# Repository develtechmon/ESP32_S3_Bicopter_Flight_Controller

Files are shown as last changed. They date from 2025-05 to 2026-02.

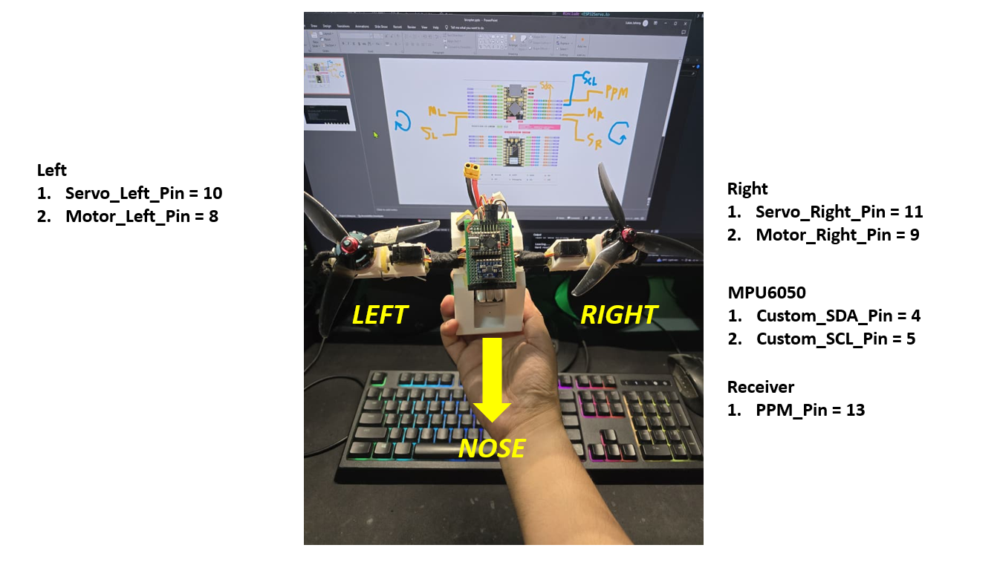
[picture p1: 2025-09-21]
Schematic/Schematic.PNG

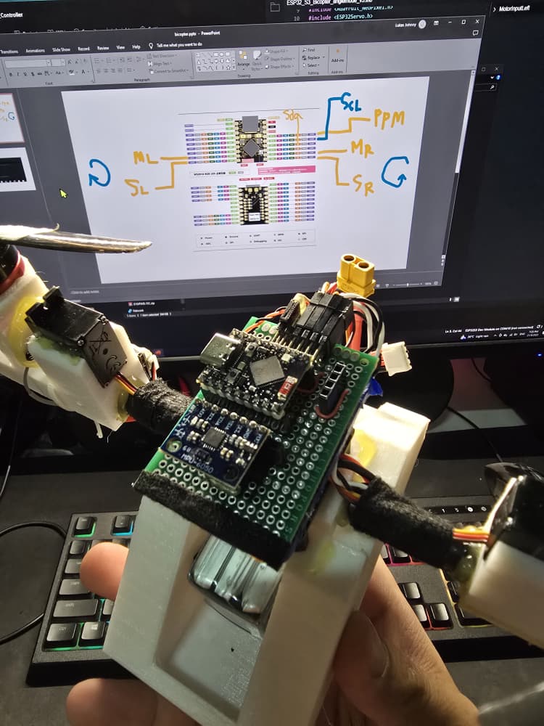
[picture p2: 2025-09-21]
Images/V2_Bicopter/2.jpeg

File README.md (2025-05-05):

# ESP32_S3_Bicopter_Flight_Controller
This is repository for EESP32_S3_Bicopter_Flight_Controller Drone. This is meant for 5inch drone build

## Components For Drone
| **Components** | **Quantity** |
|---|---|
| ESP32 S3 Super Mini | 1 |
| MPU6050 | 1 |
| Atmel 45A ESC | 2 |
| Flysky FS-A8S 2.4G 8CH | 1 |
| Servo SG90 | 2 |
| A2212/15T 930KV | 2 |
| Jumpter T-Lite V2 transmitter | 1 |
| Lipo 4S Battery | 1 |
| 3 blades 5 inch propeller | 2 |

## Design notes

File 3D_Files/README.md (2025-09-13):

This directory consist 3D stl use for this project

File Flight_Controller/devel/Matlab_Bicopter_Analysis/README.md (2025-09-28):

1. Refer to claud Bicopter PID tuning in MATLAB

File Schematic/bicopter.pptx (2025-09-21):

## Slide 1

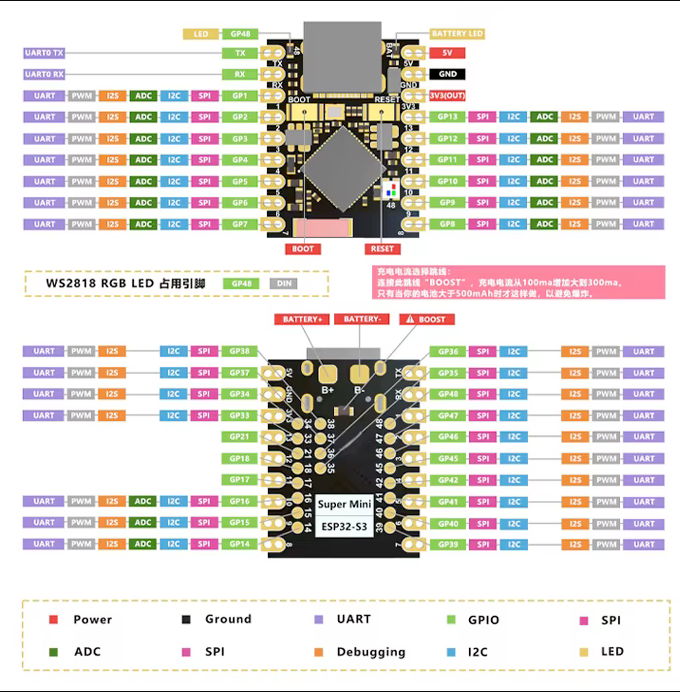
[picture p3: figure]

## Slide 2

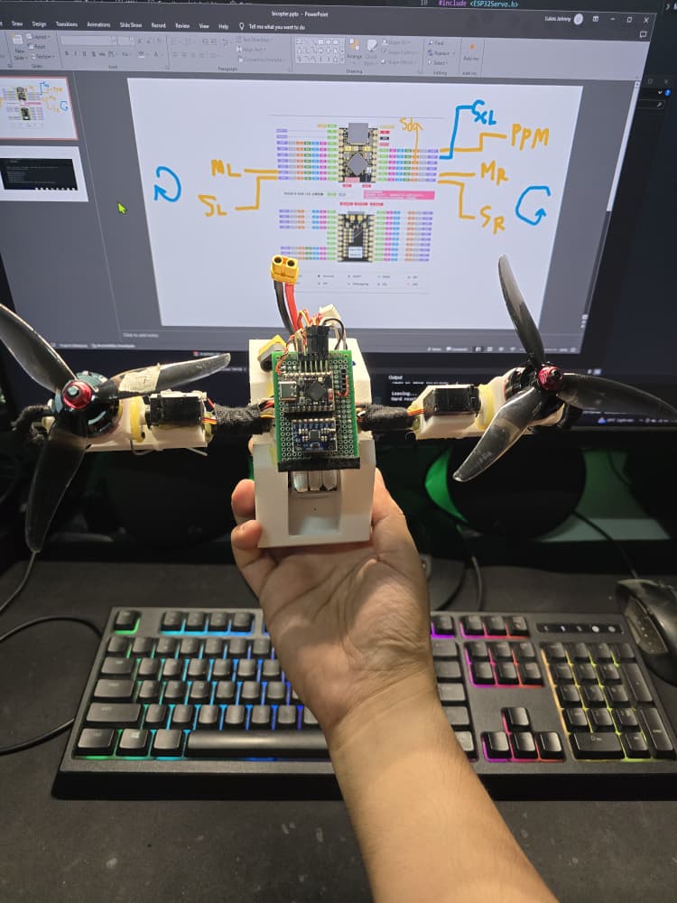
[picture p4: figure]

Left
1. Servo_Left_Pin = 10
2. Motor_Left_Pin = 8

Right
1. Servo_Right_Pin = 11
2. Motor_Right_Pin = 9

LEFT

RIGHT

MPU6050
1. Custom_SDA_Pin = 4
2. Custom_SCL_Pin = 5

Receiver
1. PPM_Pin = 13

NOSE

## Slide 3

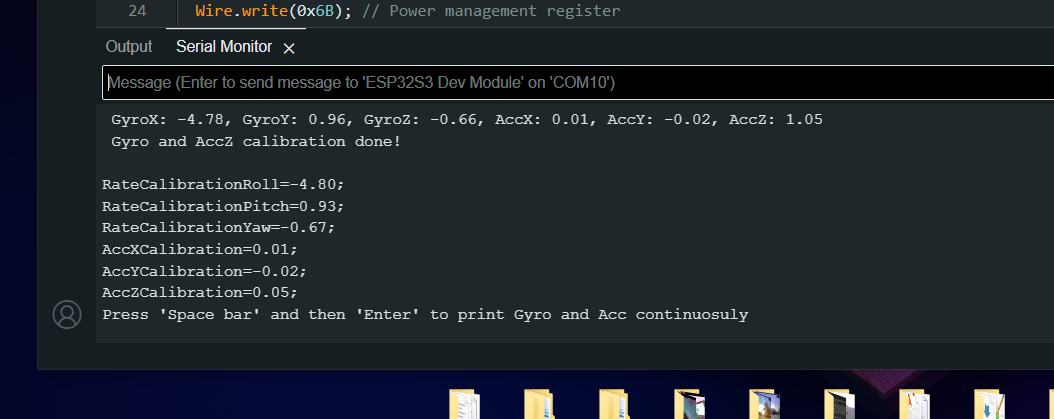
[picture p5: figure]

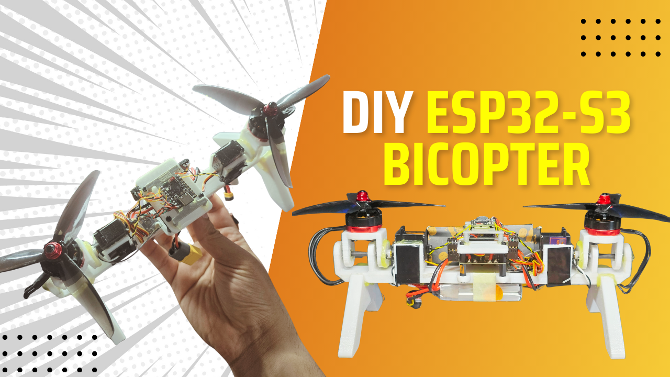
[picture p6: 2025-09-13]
Images/EsP32-S3 Flight Controller.png

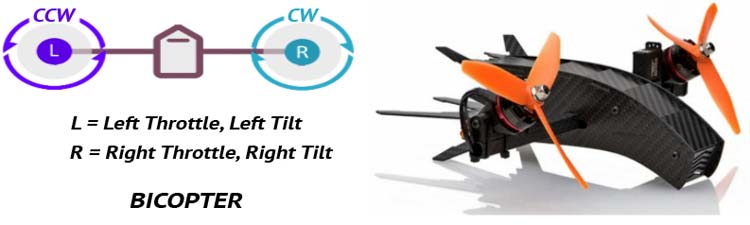
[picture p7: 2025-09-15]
Images/Bicopter-Drone-Shape.jpg

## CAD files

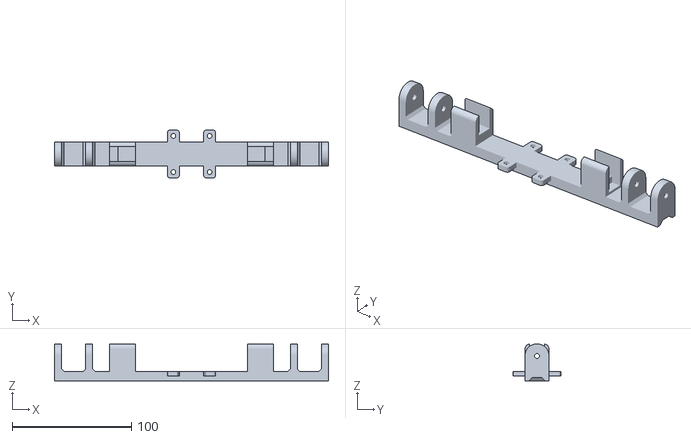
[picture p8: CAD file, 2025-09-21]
3D_Files/Bicopter_3D_STL_v2/Bicopter_Redesign_Top_Frame.stl
230.0 x 40.0 x 31.0

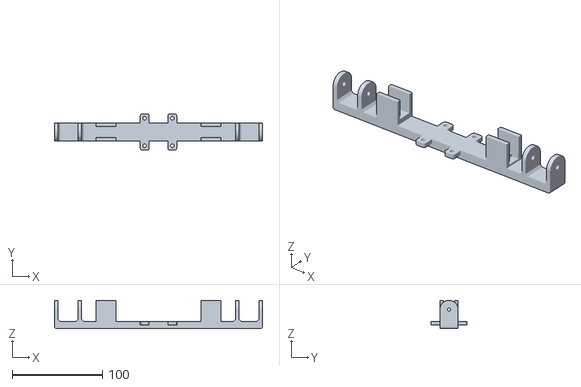
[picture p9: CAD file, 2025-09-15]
3D_Files/WIP/Bicopter_Redesign_Top_Frame.stl
230.0 x 40.0 x 31.0

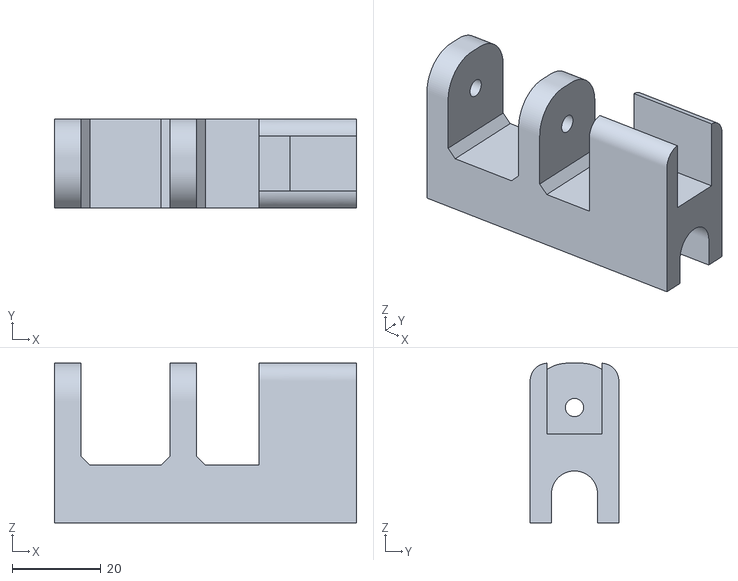
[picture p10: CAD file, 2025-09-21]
3D_Files/Bicopter_3D_STL_v2/BicopterLeft_Right_Hollow_Bottom.stl
68.1 x 20.0 x 36.0

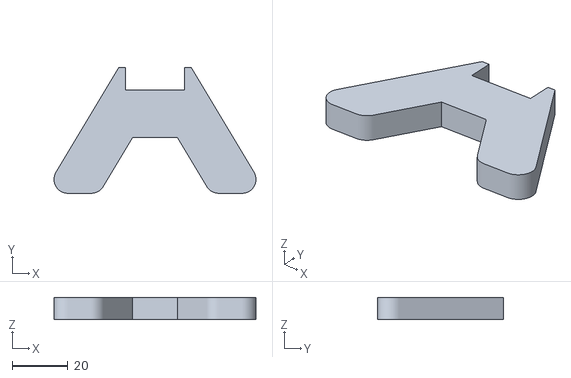
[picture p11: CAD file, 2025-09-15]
3D_Files/WIP/bicopter_leg_v3.stl
72.3 x 45.0 x 8.00

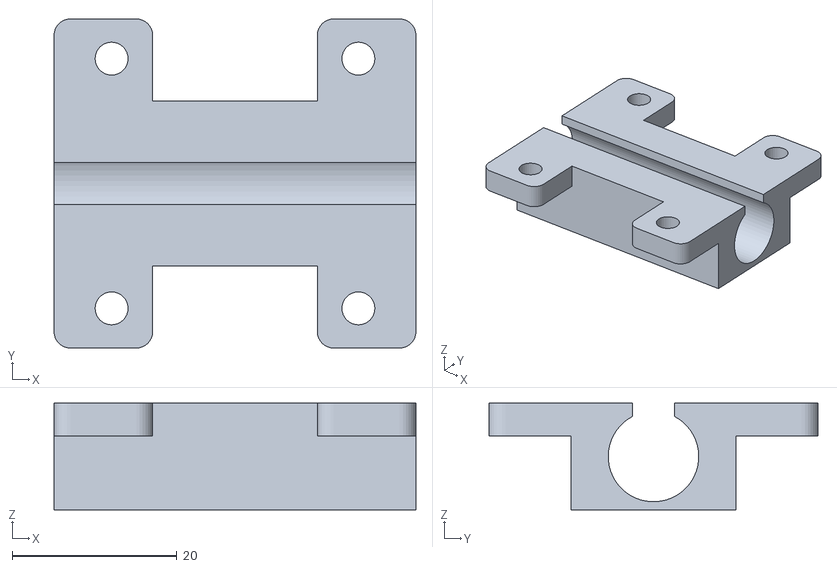
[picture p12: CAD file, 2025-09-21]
3D_Files/Bicopter_3D_STL_v2/Bicopter_FC_Middle_Holder.stl
44.0 x 40.0 x 13.0

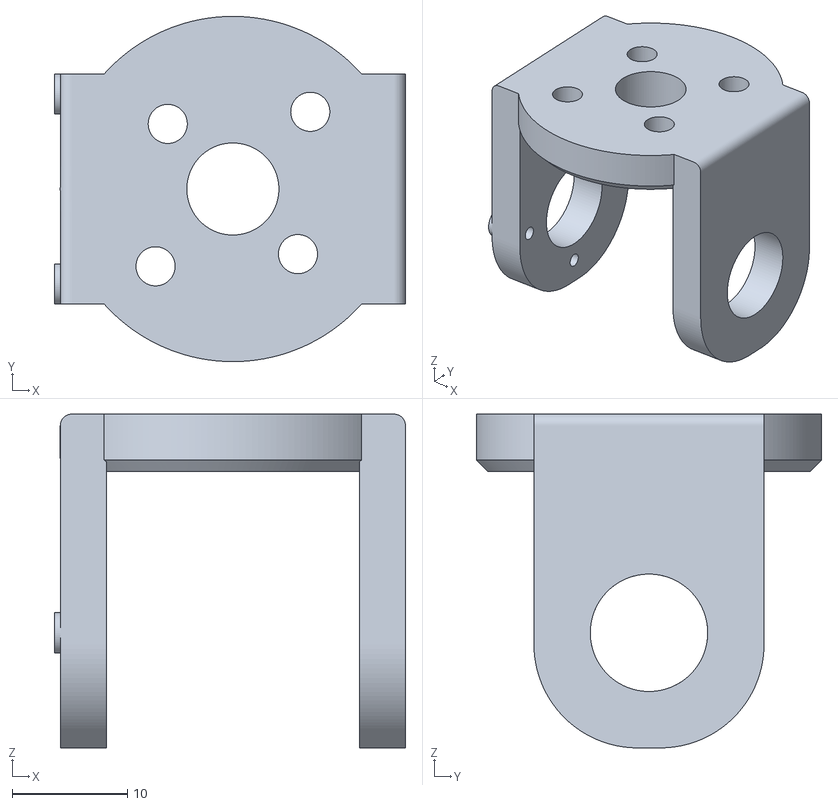
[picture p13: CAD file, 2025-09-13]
3D_Files/Bicopter_3D_STL_v2/Bicopter_Motor_section.stl
30.5 x 30.0 x 29.0

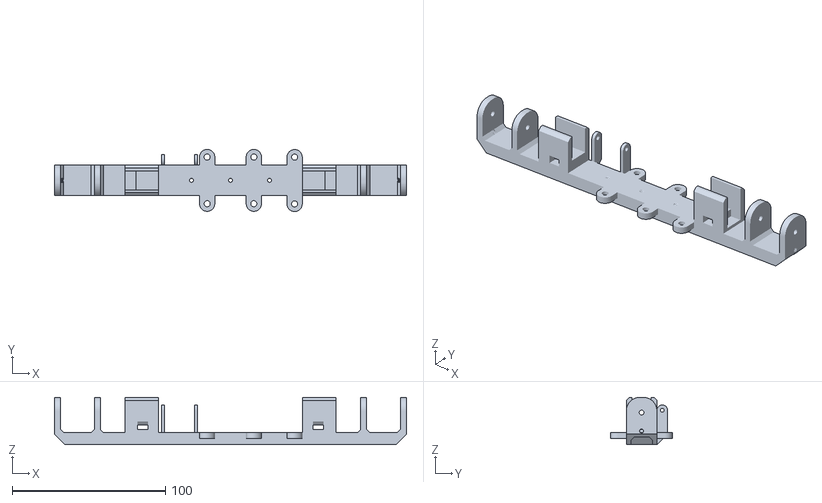
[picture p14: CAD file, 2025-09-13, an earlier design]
3D_Files/Bicopter_3D_STL_v1/Official/Bicopter_Main_Frame.stl
230.0 x 40.6 x 31.0

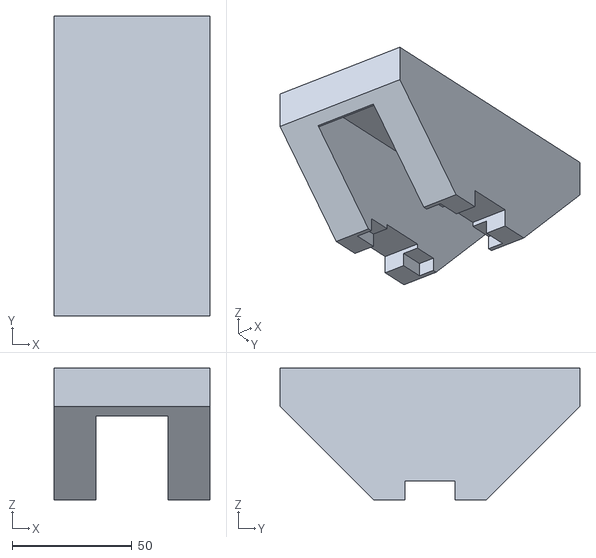
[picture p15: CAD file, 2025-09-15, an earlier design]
3D_Files/Bicopter_3D_STL_v1/Official/Bicopter_Bottom_Plate v1.stl
65.0 x 125.0 x 55.0

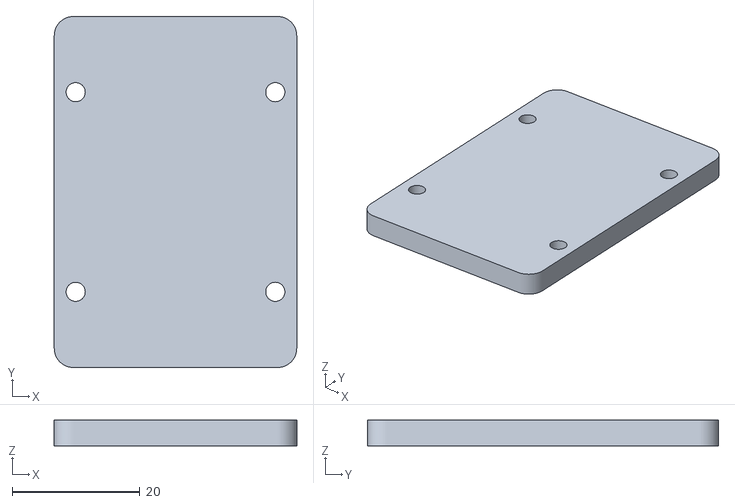
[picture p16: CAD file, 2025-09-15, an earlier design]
3D_Files/Bicopter_3D_STL_v1/Official/Bicopter_pdb_cover.stl
38.0 x 55.0 x 4.00

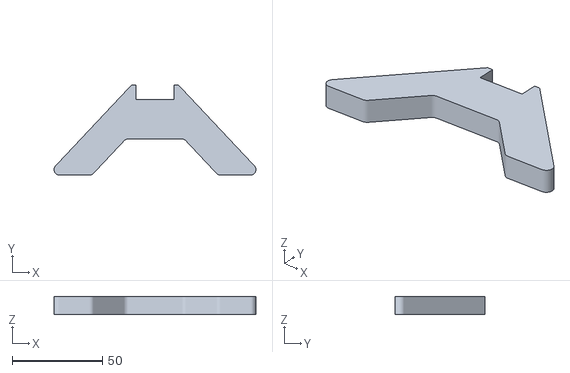
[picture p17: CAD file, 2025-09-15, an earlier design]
3D_Files/Bicopter_3D_STL_v1/Official/Bicopter_Latest_Leg_Holder.stl
112.1 x 50.0 x 10.0

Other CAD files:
3D_Files/Bicopter_3D_STL_v2/Bicopter_Left_Right_v5.stl

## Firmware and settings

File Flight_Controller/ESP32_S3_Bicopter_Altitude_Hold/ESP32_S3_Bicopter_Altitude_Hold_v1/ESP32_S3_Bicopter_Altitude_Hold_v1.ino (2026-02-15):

/*
  ================================================================================
  Project     : ESP32-S3 Bicopter Flight Controller
  File        : Bicopter_Main_Altitude_Hold.ino
  Description : Bicopter firmware with MTF-02 altitude hold.
                ALL variables declared here.
                Altitude_Hold.ino contains functions only (no declarations).

  Modules:
    Altitude_Hold.ino  — altitude hold functions
    MTF02_Library_CM.h — MTF-02 sensor library

  Bicopter layout (viewed from front):
    [Motor Left] ------- FRAME ------- [Motor Right]
         |                                    |
    [Servo Left]                       [Servo Right]

  Control mapping:
    Roll  → motor differential (left/right thrust)
    Pitch → servo tilt (forward/back)
    Yaw   → opposite servo tilt

  Channels:
    CH1 → Roll
    CH2 → Pitch
    CH3 → Throttle
    CH4 → Yaw
    CH5 → Arm/Disarm (yaw right = arm, yaw left = disarm)
    CH6 → Altitude Hold on/off (> 1500 = ON)

  Revision History:
    Version  Date        Author        Description
    -------  ----------  ------------  -----------------------------------------
    1.0      2025-07-30  Lukas Johnny  Initial bicopter release
    1.1      2025-08-15  Lukas Johnny  Added MTF-02 altitude hold module
  ================================================================================
*/

#include <Wire.h>
#include <math.h>
#include <Adafruit_NeoPixel.h>
#include <ESP32Servo.h>
#include "MTF02_Library_CM.h"

// ==== Pin Definitions ====
#define LED_PIN         48
#define NUM_LEDS        1
#define PPM_PIN         13
#define CUSTOM_SDA_PIN  4
#define CUSTOM_SCL_PIN  5
#define SERVO_RIGHT_PIN 11
#define SERVO_LEFT_PIN  10
#define MOTOR_RIGHT_PIN 9
#define MOTOR_LEFT_PIN  8

// ==== PPM Configuration ====
#define NUM_CHANNELS       8
#define PPM_SYNC_THRESHOLD 3000
#define CHANNEL_MIN        1000
#define CHANNEL_MAX        2000

// ==== Servo Configuration ====
#define SERVO_CENTER 1500
#define SERVO_MIN    1200
#define SERVO_MAX    1800

// ==== ESC Configuration ====
int ESCfreq        = 400;
int ThrottleIdle   = 1180;
int ThrottleCutOff = 1000;

// ==== Timing ====
const float dt = 0.004;   // 250Hz
uint32_t LoopTimer;

// ==== LED ====
Adafruit_NeoPixel strip(NUM_LEDS, LED_PIN, NEO_GRB + NEO_KHZ800);

// ==== Servo and Motor Objects ====
Servo servoRight;
Servo servoLeft;
Servo motorRight;
Servo motorLeft;

// ==== Receiver Variables ====
volatile int ReceiverValue[NUM_CHANNELS] = {1500,1500,1000,1500,1500,1500,1500,1500};
volatile int channelIndex = 0;
volatile unsigned long lastTime = 0;
int channelValues[NUM_CHANNELS];

// ==== IMU Variables ====
float RateRoll, RatePitch, RateYaw;
float AccX, AccY, AccZ;
float AngleRoll, AnglePitch;
float KalmanAngleRoll             = 0;
float KalmanUncertaintyAngleRoll  = 4;
float KalmanAnglePitch            = 0;
float KalmanUncertaintyAnglePitch = 4;
volatile float Kalman1DOutput[]   = {0, 0};

// ==== Calibration Values ====
float RateCalibrationRoll  =  1.73;
float RateCalibrationPitch = -0.30;
float RateCalibrationYaw   =  0.39;
float AccXCalibration      =  0.01;
float AccYCalibration      = -0.03;
float AccZCalibration      =  0.08;

// ==== Angle PID Gains ====
float PAngleRoll  = 1.5,  IAngleRoll  = 0.3,  DAngleRoll  = 0.01;
float PAnglePitch = 1.5,  IAnglePitch = 0.3,  DAnglePitch = 0.01;

// ==== Rate PID Gains ====
float PRateRoll  = 0.5,  IRateRoll  = 1.5,  DRateRoll  = 0.008;
float PRatePitch = 0.5,  IRatePitch = 1.5,  DRatePitch = 0.008;
float PRateYaw   = 0.8,  IRateYaw   = 1.2,  DRateYaw   = 0.005;

// ==== PID State Variables ====
float DesiredAngleRoll,  DesiredAnglePitch;
float ErrorAngleRoll,    ErrorAnglePitch;
float PrevErrorAngleRoll  = 0,  PrevErrorAnglePitch  = 0;
float PrevItermAngleRoll  = 0,  PrevItermAnglePitch  = 0;

float DesiredRateRoll,  DesiredRatePitch,  DesiredRateYaw;
float ErrorRateRoll,    ErrorRatePitch,    ErrorRateYaw;
float PrevErrorRateRoll  = 0,  PrevErrorRatePitch  = 0,  PrevErrorRateYaw  = 0;
float PrevItermRateRoll  = 0,  PrevItermRatePitch  = 0,  PrevItermRateYaw  = 0;

float InputRoll, InputPitch, InputYaw, InputThrottle;
float MotorInputRight, MotorInputLeft;
float ServoInputRight, ServoInputLeft;

// ==== Servo Filtering ====
float filteredServoLeft  = SERVO_CENTER;
float filteredServoRight = SERVO_CENTER;
const float SERVO_ALPHA  = 0.6;

// ==== D-term Filtering ====
float filteredDRatePitch = 0;
float filteredDRateYaw   = 0;
const float D_FILTER_ALPHA = 0.15;

// ==== Servo Rate Limiting ====
float prevServoLeft  = SERVO_CENTER;
float prevServoRight = SERVO_CENTER;
const float MAX_SERVO_RATE = 30;

// ==== Arming ====
bool armed = false;
unsigned long armDisarmTimer = 0;
const unsigned long armHoldTime = 1000;

// ================================================================================
// ALTITUDE HOLD VARIABLES (used by Altitude_Hold.ino functions)
// ================================================================================

// MTF-02 filtering
#define LIDAR_BUFFER_SIZE 21
int   lidarHistTab[LIDAR_BUFFER_SIZE];
int   lidarHistIdx        = 0;
int   lidarSum            = 0;
float complementaryFiltered = 0;
const float COMP_FILTER_ALPHA = 0.75;

// Altitude hold state
bool  altitudeHoldActive  = false;
float groundReference     = 0;
float targetAltitude      = 0;
float currentAltitude     = 0;
int   baseThrottle        = 0;

// Landing mode
bool  landingMode             = false;
float landingStartAltitude    = 0;
unsigned long landingStartTime = 0;
const float LANDING_RATE_CMS          = 15.0;
const int   THROTTLE_DEADBAND         = 25;
const int   LANDING_THROTTLE_THRESHOLD = 1400;

// Altitude PID
float altPID_error       = 0;
float altPID_errorPrev   = 0;
float altPID_integral    = 0;
float altPID_output      = 0;
float altPID_Kp          = 1.0;
float altPID_Ki          = 0.25;
float altPID_Kd          = 0.5;
float altPID_integralMax = 100.0;

// Velocity-based derivative
float altitudeVelocity        = 0;
unsigned long altitudeHoldStartTime = 0;

// ================================================================================
// FUNCTION PROTOTYPES
// ================================================================================
void IRAM_ATTR ppmInterruptHandler();
void read_receiver();
void read_imu();
void kalman_1d(float& KalmanState, float& KalmanUncertainty,
               float KalmanInput, float KalmanMeasurement);
void reset_pid();
float constrain_float(float value, float min_val, float max_val);
float rate_limit(float current, float previous, float max_rate);

// ================================================================================
// PPM INTERRUPT
// ================================================================================
void IRAM_ATTR ppmInterruptHandler() {
  unsigned long currentTime = micros();
  unsigned long pulseWidth  = currentTime - lastTime;
  lastTime = currentTime;
  if (pulseWidth > PPM_SYNC_THRESHOLD) {
    channelIndex = 0;
  } else if (channelIndex < NUM_CHANNELS) {
    if (pulseWidth < CHANNEL_MIN) pulseWidth = CHANNEL_MIN;
    else if (pulseWidth > CHANNEL_MAX) pulseWidth = CHANNEL_MAX;
    ReceiverValue[channelIndex] = pulseWidth;
    channelIndex++;
  }
}

// ================================================================================
// READ RECEIVER
// ================================================================================
void read_receiver() {
  noInterrupts();
  for (int i = 0; i < NUM_CHANNELS; i++) channelValues[i] = ReceiverValue[i];
  interrupts();
}

// ================================================================================
// KALMAN FILTER
// ================================================================================
void kalman_1d(float& KalmanState, float& KalmanUncertainty,
               float KalmanInput, float KalmanMeasurement) {
  KalmanState       = KalmanState + dt * KalmanInput;
  KalmanUncertainty = KalmanUncertainty + dt * dt * 4 * 4;
  float KalmanGain  = KalmanUncertainty / (KalmanUncertainty + 3 * 3);
  KalmanState       = KalmanState + KalmanGain * (KalmanMeasurement - KalmanState);
  KalmanUncertainty = (1 - KalmanGain) * KalmanUncertainty;
  Kalman1DOutput[0] = KalmanState;
  Kalman1DOutput[1] = KalmanUncertainty;
}

// ================================================================================
// READ IMU
// ================================================================================
void read_imu() {
  Wire.beginTransmission(0x68); Wire.write(0x1A); Wire.write(0x05); Wire.endTransmission();
  Wire.beginTransmission(0x68); Wire.write(0x1C); Wire.write(0x10); Wire.endTransmission();
  Wire.beginTransmission(0x68); Wire.write(0x3B); Wire.endTransmission();
  Wire.requestFrom(0x68, 6);
  int16_t AccXLSB = Wire.read() << 8 | Wire.read();
  int16_t AccYLSB = Wire.read() << 8 | Wire.read();
  int16_t AccZLSB = Wire.read() << 8 | Wire.read();

  Wire.beginTransmission(0x68); Wire.write(0x1B); Wire.write(0x08); Wire.endTransmission();
  Wire.beginTransmission(0x68); Wire.write(0x43); Wire.endTransmission();
  Wire.requestFrom(0x68, 6);
  int16_t GyroX = Wire.read() << 8 | Wire.read();
  int16_t GyroY = Wire.read() << 8 | Wire.read();
  int16_t GyroZ = Wire.read() << 8 | Wire.read();

  RateRoll  = (float)GyroX / 65.5 - RateCalibrationRoll;
  RatePitch = (float)GyroY / 65.5 - RateCalibrationPitch;
  RateYaw   = (float)GyroZ / 65.5 - RateCalibrationYaw;
  AccX = (float)AccXLSB / 4096 - AccXCalibration;
  AccY = (float)AccYLSB / 4096 - AccYCalibration;
  AccZ = (float)AccZLSB / 4096 - AccZCalibration;
  AngleRoll  = atan(AccY / sqrt(AccX * AccX + AccZ * AccZ)) * 57.29578;
  AnglePitch = -atan(AccX / sqrt(AccY * AccY + AccZ * AccZ)) * 57.29578;
}

// ================================================================================
// RESET PID
// ================================================================================
void reset_pid() {
  PrevErrorAngleRoll = 0;  PrevErrorAnglePitch = 0;
  PrevItermAngleRoll = 0;  PrevItermAnglePitch = 0;
  PrevErrorRateRoll  = 0;  PrevErrorRatePitch  = 0;  PrevErrorRateYaw  = 0;
  PrevItermRateRoll  = 0;  PrevItermRatePitch  = 0;  PrevItermRateYaw  = 0;
  filteredServoLeft  = SERVO_CENTER;  filteredServoRight = SERVO_CENTER;
  prevServoLeft      = SERVO_CENTER;  prevServoRight     = SERVO_CENTER;
  filteredDRatePitch = 0;
  filteredDRateYaw   = 0;
}

// ================================================================================
// HELPERS
// ================================================================================
float constrain_float(float value, float min_val, float max_val) {
  if (value < min_val) return min_val;
  if (value > max_val) return max_val;
  return value;
}

float rate_limit(float current, float previous, float max_rate) {
  float delta = current - previous;
  if (abs(delta) > max_rate) return (delta > 0) ? previous + max_rate : previous - max_rate;
  return current;
}

// ================================================================================
// SETUP
// ================================================================================
void setup() {
  Serial.begin(115200);
  Serial.println("Bicopter Starting...");

  pinMode(LED_BUILTIN, OUTPUT);
  pinMode(2, OUTPUT);
  strip.begin();
  strip.show();

  for (int i = 0; i < 4; i++) {
    digitalWrite(LED_BUILTIN, HIGH); delay(100);
    digitalWrite(LED_BUILTIN, LOW);  delay(100);
  }

  pinMode(PPM_PIN, INPUT);
  attachInterrupt(digitalPinToInterrupt(PPM_PIN), ppmInterruptHandler, FALLING);
  delay(100);

  Wire.setClock(400000);
  Wire.begin(CUSTOM_SDA_PIN, CUSTOM_SCL_PIN);
  delay(250);
  Wire.beginTransmission(0x68); Wire.write(0x6B); Wire.write(0x00); Wire.endTransmission();
  delay(100);

  // MTF-02 init + ground calibration (Altitude_Hold.ino)
  initializeAltitudeSystem();

  ESP32PWM::allocateTimer(0); ESP32PWM::allocateTimer(1);
  ESP32PWM::allocateTimer(2); ESP32PWM::allocateTimer(3);

  Serial.println("Initializing ESCs...");
  delay(1000);
  motorRight.attach(MOTOR_RIGHT_PIN, 1000, 2000); delay(500); motorRight.setPeriodHertz(ESCfreq);
  motorLeft.attach(MOTOR_LEFT_PIN,   1000, 2000); delay(500); motorLeft.setPeriodHertz(ESCfreq);
  motorRight.writeMicroseconds(1000);
  motorLeft.writeMicroseconds(1000);
  delay(2000);

  servoRight.setPeriodHertz(200); servoLeft.setPeriodHertz(200);
  servoRight.attach(SERVO_RIGHT_PIN, SERVO_MIN, SERVO_MAX);
  servoLeft.attach(SERVO_LEFT_PIN,   SERVO_MIN, SERVO_MAX);
  servoRight.writeMicroseconds(SERVO_CENTER);
  servoLeft.writeMicroseconds(SERVO_CENTER);
  delay(1000);

  filteredServoLeft  = SERVO_CENTER; filteredServoRight = SERVO_CENTER;
  prevServoLeft      = SERVO_CENTER; prevServoRight     = SERVO_CENTER;

  strip.setPixelColor(0, strip.Color(0, 255, 0)); strip.show(); delay(1000);
  strip.setPixelColor(0, strip.Color(0, 0, 0));   strip.show();

  Serial.println("Setup complete!");
  LoopTimer = micros();
}

// ================================================================================
// MAIN LOOP
// ================================================================================
void loop() {
  read_receiver();

  // ---- Arming / Disarming ----
  if (channelValues[2] < 1050) {
    if (!armed && channelValues[3] > 1900) {
      if (armDisarmTimer == 0) armDisarmTimer = millis();
      else if (millis() - armDisarmTimer > armHoldTime) {
        armed = true;
        strip.setPixelColor(0, strip.Color(255, 255, 0)); strip.show(); delay(500);
        strip.setPixelColor(0, strip.Color(0, 0, 0));     strip.show();
        armDisarmTimer = 0;
        Serial.println("ARMED");
      }
    } else if (armed && channelValues[3] < 1100) {
      if (armDisarmTimer == 0) armDisarmTimer = millis();
      else if (millis() - armDisarmTimer > armHoldTime) {
        armed              = false;
        altitudeHoldActive = false;
        landingMode        = false;
        strip.setPixelColor(0, strip.Color(255, 255, 255)); strip.show(); delay(500);
        strip.setPixelColor(0, strip.Color(0, 0, 0));       strip.show();
        armDisarmTimer = 0;
        reset_pid();
        Serial.println("DISARMED");
      }
    } else { armDisarmTimer = 0; }
  } else { armDisarmTimer = 0; }

  // ---- Disarmed: stop everything ----
  if (!armed) {
    motorRight.writeMicroseconds(ThrottleCutOff);
    motorLeft.writeMicroseconds(ThrottleCutOff);
    servoRight.writeMicroseconds(SERVO_CENTER);
    servoLeft.writeMicroseconds(SERVO_CENTER);
    while (micros() - LoopTimer < (dt * 1000000));
    LoopTimer = micros();
    return;
  }

  // ---- Altitude Hold (Altitude_Hold.ino) ----
  a_updateAltitude();
  b_handleAltitudeHold();
  c_handlePilotAltitudeInput();
  d_calculateAltitudePID();

  // ---- IMU ----
  read_imu();

  // ---- Kalman ----
  kalman_1d(KalmanAngleRoll,  KalmanUncertaintyAngleRoll,  RateRoll,  AngleRoll);
  KalmanAngleRoll            = Kalman1DOutput[0];
  KalmanUncertaintyAngleRoll = Kalman1DOutput[1];
  kalman_1d(KalmanAnglePitch, KalmanUncertaintyAnglePitch, RatePitch, AnglePitch);
  KalmanAnglePitch            = Kalman1DOutput[0];
  KalmanUncertaintyAnglePitch = Kalman1DOutput[1];
  KalmanAngleRoll  = constrain_float(KalmanAngleRoll,  -20, 20);
  KalmanAnglePitch = constrain_float(KalmanAnglePitch, -20, 20);

  // ---- Desired Angles ----
  DesiredAngleRoll  = 0.1  * (channelValues[0] - 1500);
  DesiredAnglePitch = 0.1  * (channelValues[1] - 1500);
  DesiredRateYaw    = 0.15 * (channelValues[3] - 1500);

  // ---- Throttle ----
  InputThrottle = calculateThrottleOutput();

  // ---- Angle PID: Roll ----
  ErrorAngleRoll = DesiredAngleRoll - KalmanAngleRoll;
  float PtAR = PAngleRoll * ErrorAngleRoll;
  float ItAR = PrevItermAngleRoll + IAngleRoll * (ErrorAngleRoll + PrevErrorAngleRoll) * dt / 2;
  ItAR = constrain_float(ItAR, -200, 200);
  float DtAR = DAngleRoll * (ErrorAngleRoll - PrevErrorAngleRoll) / dt;
  DesiredRateRoll = constrain_float(PtAR + ItAR + DtAR, -200, 200);
  PrevErrorAngleRoll = ErrorAngleRoll; PrevItermAngleRoll = ItAR;

  // ---- Angle PID: Pitch ----
  ErrorAnglePitch = DesiredAnglePitch - KalmanAnglePitch;
  float PtAP = PAnglePitch * ErrorAnglePitch;
  float ItAP = PrevItermAnglePitch + IAnglePitch * (ErrorAnglePitch + PrevErrorAnglePitch) * dt / 2;
  ItAP = constrain_float(ItAP, -200, 200);
  float DtAP = DAnglePitch * (ErrorAnglePitch - PrevErrorAnglePitch) / dt;
  DesiredRatePitch = constrain_float(PtAP + ItAP + DtAP, -200, 200);
  PrevErrorAnglePitch = ErrorAnglePitch; PrevItermAnglePitch = ItAP;

  // ---- Rate PID: Roll ----
  ErrorRateRoll = DesiredRateRoll - RateRoll;
  float PtRR = PRateRoll * ErrorRateRoll;
  float ItRR = PrevItermRateRoll + IRateRoll * (ErrorRateRoll + PrevErrorRateRoll) * dt / 2;
  ItRR = constrain_float(ItRR, -300, 300);
  float DtRR = DRateRoll * (ErrorRateRoll - PrevErrorRateRoll) / dt;
  InputRoll = constrain_float(PtRR + ItRR + DtRR, -400, 400);
  PrevErrorRateRoll = ErrorRateRoll; PrevItermRateRoll = ItRR;

  // ---- Rate PID: Pitch ----
  ErrorRatePitch = DesiredRatePitch - RatePitch;
  float PtRP = PRatePitch * ErrorRatePitch;
  float ItRP = PrevItermRatePitch + IRatePitch * (ErrorRatePitch + PrevErrorRatePitch) * dt / 2;
  ItRP = constrain_float(ItRP, -300, 300);
  float DtRP = DRatePitch * (ErrorRatePitch - PrevErrorRatePitch) / dt;
  filteredDRatePitch = D_FILTER_ALPHA * DtRP + (1 - D_FILTER_ALPHA) * filteredDRatePitch;
  InputPitch = constrain_float(PtRP + ItRP + filteredDRatePitch, -400, 400);
  PrevErrorRatePitch = ErrorRatePitch; PrevItermRatePitch = ItRP;

  // ---- Rate PID: Yaw ----
  ErrorRateYaw = DesiredRateYaw - RateYaw;
  float PtRY = PRateYaw * ErrorRateYaw;
  float ItRY = PrevItermRateYaw + IRateYaw * (ErrorRateYaw + PrevErrorRateYaw) * dt / 2;
  ItRY = constrain_float(ItRY, -300, 300);
  float DtRY = DRateYaw * (ErrorRateYaw - PrevErrorRateYaw) / dt;
  filteredDRateYaw = D_FILTER_ALPHA * DtRY + (1 - D_FILTER_ALPHA) * filteredDRateYaw;
  InputYaw = constrain_float(PtRY + ItRY + filteredDRateYaw, -400, 400);
  PrevErrorRateYaw = ErrorRateYaw; PrevItermRateYaw = ItRY;

  if (InputThrottle > 1800) InputThrottle = 1800;

  // ---- Bicopter Mixing ----
  MotorInputLeft  = InputThrottle - InputRoll;
  MotorInputRight = InputThrottle + InputRoll;
  ServoInputLeft  = SERVO_CENTER - InputPitch * 1.5 - InputYaw * 1;
  ServoInputRight = SERVO_CENTER + InputPitch * 1.5 - InputYaw * 1;

  // ---- Servo Rate Limit + Filter ----
  ServoInputLeft  = rate_limit(ServoInputLeft,  prevServoLeft,  MAX_SERVO_RATE);
  ServoInputRight = rate_limit(ServoInputRight, prevServoRight, MAX_SERVO_RATE);
  filteredServoLeft  = SERVO_ALPHA * ServoInputLeft  + (1 - SERVO_ALPHA) * filteredServoLeft;
  filteredServoRight = SERVO_ALPHA * ServoInputRight + (1 - SERVO_ALPHA) * filteredServoRight;
  filteredServoLeft  = constrain_float(filteredServoLeft,  SERVO_MIN, SERVO_MAX);
  filteredServoRight = constrain_float(filteredServoRight, SERVO_MIN, SERVO_MAX);
  prevServoLeft  = ServoInputLeft;
  prevServoRight = ServoInputRight;

  // ---- Motor Limits ----
  MotorInputRight = constrain_float(MotorInputRight, ThrottleIdle, 2000);
  MotorInputLeft  = constrain_float(MotorInputLeft,  ThrottleIdle, 2000);

  // ---- Emergency Stop ----
  if (channelValues[2] < 1030) {
    MotorInputRight    = ThrottleCutOff;
    MotorInputLeft     = ThrottleCutOff;
    filteredServoLeft  = SERVO_CENTER;
    filteredServoRight = SERVO_CENTER;
    prevServoLeft      = SERVO_CENTER;
    prevServoRight     = SERVO_CENTER;
    altitudeHoldActive = false;
    landingMode        = false;
    reset_pid();
  }

  // ---- Write Outputs ----
  motorRight.writeMicroseconds((int)MotorInputRight);
  motorLeft.writeMicroseconds((int)MotorInputLeft);
  servoRight.writeMicroseconds((int)filteredServoRight);
  servoLeft.writeMicroseconds((int)filteredServoLeft);

  while (micros() - LoopTimer < (dt * 1000000));
  LoopTimer = micros();
}

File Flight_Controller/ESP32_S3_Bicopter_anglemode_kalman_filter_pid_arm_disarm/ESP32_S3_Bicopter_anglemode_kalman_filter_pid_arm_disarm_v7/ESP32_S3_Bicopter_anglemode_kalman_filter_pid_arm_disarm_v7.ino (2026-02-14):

 /*
  Bicopter Flight Controller - Stable Version
  ESP32-S3 with MPU6050, 2 servos, 2 motors
  Tested for Arduino IDE compilation
*/

#include <Wire.h>
#include <math.h>
#include <Adafruit_NeoPixel.h>
#include <ESP32Servo.h>

// ==== Pin Definitions ====
#define LED_PIN 48  
#define NUM_LEDS 1
#define PPM_PIN 13
// #define CUSTOM_SDA_PIN 11
// #define CUSTOM_SCL_PIN 12
// #define SERVO_RIGHT_PIN 8
// #define SERVO_LEFT_PIN 7
// #define MOTOR_RIGHT_PIN 9
// #define MOTOR_LEFT_PIN 6

#define CUSTOM_SDA_PIN 4
#define CUSTOM_SCL_PIN 5
#define SERVO_RIGHT_PIN 11
#define SERVO_LEFT_PIN 10
#define MOTOR_RIGHT_PIN 9
#define MOTOR_LEFT_PIN 8

// ==== PPM Configuration ====
#define NUM_CHANNELS 8
#define PPM_SYNC_THRESHOLD 3000
#define CHANNEL_MIN 1000
#define CHANNEL_MAX 2000

// ==== Servo Configuration ====
#define SERVO_CENTER 1500
#define SERVO_MIN 1200
#define SERVO_MAX 1800

// ==== ESC Configuration ====
int ESCfreq = 400;
int ThrottleIdle = 1180;
int ThrottleCutOff = 1000;

// ==== Timing ====
const float dt = 0.004;  // 250Hz loop rate
uint32_t LoopTimer;

// ==== LED ====
Adafruit_NeoPixel strip(NUM_LEDS, LED_PIN, NEO_GRB + NEO_KHZ800);

// ==== Servo and Motor Objects ====
Servo servoRight;
Servo servoLeft;
Servo motorRight;
Servo motorLeft;

// ==== Receiver Variables ====
volatile int ReceiverValue[NUM_CHANNELS] = {1500,1500,1000,1500,1500,1500,1500,1500};
volatile int channelIndex = 0;
volatile unsigned long lastTime = 0;
int channelValues[NUM_CHANNELS];

// ==== IMU Variables ====
float RateRoll, RatePitch, RateYaw;
float AccX, AccY, AccZ;
float AngleRoll, AnglePitch;
float KalmanAngleRoll = 0;
float KalmanUncertaintyAngleRoll = 4;
float KalmanAnglePitch = 0;
float KalmanUncertaintyAnglePitch = 4;
volatile float Kalman1DOutput[] = {0,0};

// ==== Calibration Values ====
// float RateCalibrationRoll = -1.95;
// float RateCalibrationPitch = 1.86;
// float RateCalibrationYaw = 0.32;
// float AccXCalibration = 0.02;
// float AccYCalibration = 0.01;
// float AccZCalibration = 0.08;

// float RateCalibrationRoll = -5.14;
// float RateCalibrationPitch = 1.03;
// float RateCalibrationYaw = -0.84;
// float AccXCalibration = 0.04;
// float AccYCalibration = 0.01;
// float AccZCalibration = 0.05;

float RateCalibrationRoll = 1.73;
float RateCalibrationPitch = -0.30;
float RateCalibrationYaw = 0.39;
float AccXCalibration = 0.01;
float AccYCalibration = -0.03;
float AccZCalibration = 0.08;

// ==== PID Gains ====
float PAngleRoll = 1.5;
float IAngleRoll = 0.3;
float DAngleRoll = 0.01;
float PAnglePitch = PAngleRoll;
float IAnglePitch = IAngleRoll;
float DAnglePitch = DAngleRoll;

// Rate PID (inner loop)
float PRateRoll = 0.5;
float IRateRoll = 1.5;
float DRateRoll = 0.008;
float PRatePitch = PRateRoll;
float IRatePitch = IRateRoll;
float DRatePitch = DRateRoll;
float PRateYaw = 0.8;
float IRateYaw = 1.2;
float DRateYaw = 0.005;

// float PAngleRoll = 1.0;
// float IAngleRoll = 0.1;
// float DAngleRoll = 0.005;
// float PAnglePitch = PAngleRoll;
// float IAnglePitch = IAngleRoll;
// float DAnglePitch = DAngleRoll;

// // Rate PID (inner loop)
// float PRateRoll = 0.3;
// float IRateRoll = 0.8;
// float DRateRoll = 0.004;
// float PRatePitch = PRateRoll;
// float IRatePitch = IRateRoll;
// float DRatePitch = DRateRoll;
// float PRateYaw = 0.4;
// float IRateYaw = 1.6;
// float DRateYaw = 0.002;

// float PAngleRoll = 1.2;
// float IAngleRoll = 0.15;
// float DAngleRoll = 0.02;
// float PAnglePitch = PAngleRoll;
// float IAnglePitch = IAngleRoll;
// float DAnglePitch = DAngleRoll;

// // Rate PID (inner loop)
// float PRateRoll = 0.4;
// float IRateRoll = 1.0;
// float DRateRoll = 0.01;
// float PRatePitch = PRateRoll;
// float IRatePitch = IRateRoll;
// float DRatePitch = DRateRoll;
// float PRateYaw = 0.6;
// float IRateYaw = 1.8;
// float DRateYaw = 0.008;

// ==== PID Variables ====
float DesiredAngleRoll, DesiredAnglePitch;
float ErrorAngleRoll, ErrorAnglePitch;
float PrevErrorAngleRoll = 0, PrevErrorAnglePitch = 0;
float PrevItermAngleRoll = 0, PrevItermAnglePitch = 0;

float DesiredRateRoll, DesiredRatePitch, DesiredRateYaw;
float ErrorRateRoll, ErrorRatePitch, ErrorRateYaw;
float PrevErrorRateRoll = 0, PrevErrorRatePitch = 0, PrevErrorRateYaw = 0;
float PrevItermRateRoll = 0, PrevItermRatePitch = 0, PrevItermRateYaw = 0;

float InputRoll, InputPitch, InputYaw, InputThrottle;
float MotorInputRight, MotorInputLeft;
float ServoInputRight, ServoInputLeft;

// ==== Servo Filtering Variables ====
float filteredServoLeft = SERVO_CENTER;
float filteredServoRight = SERVO_CENTER;
//const float SERVO_ALPHA = 0.75;  // This is your main tuning parameter
const float SERVO_ALPHA = 0.6;  // This is your main tuning parameter

// ==== Derivative Filtering ====
float filteredDRatePitch = 0;
float filteredDRateYaw = 0;
const float D_FILTER_ALPHA = 0.15;  // Strong filtering for D-terms

// ==== Rate Limiting for Servos ====
float prevServoLeft = SERVO_CENTER;
float prevServoRight = SERVO_CENTER;
//const float MAX_SERVO_RATE = 100;  // Max microseconds change per loop
// const float MAX_SERVO_RATE = 50;  // Max microseconds change per loop
const float MAX_SERVO_RATE = 30;  // Max microseconds change per loop

// ==== Arming Variables ====
bool armed = false;
unsigned long armDisarmTimer = 0;
const unsigned long armHoldTime = 1000;

// ==== Function Prototypes ====
void IRAM_ATTR ppmInterruptHandler();
void read_receiver();
void read_imu();
void kalman_1d(float& KalmanState, float& KalmanUncertainty, float KalmanInput, float KalmanMeasurement);
void reset_pid();
float constrain_float(float value, float min_val, float max_val);
float rate_limit(float current, float previous, float max_rate);

// ==== PPM Interrupt Handler ====
void IRAM_ATTR ppmInterruptHandler() {
  unsigned long currentTime = micros();
  unsigned long pulseWidth = currentTime - lastTime;
  lastTime = currentTime;

  if (pulseWidth > PPM_SYNC_THRESHOLD) {
    channelIndex = 0;
  } else if (channelIndex < NUM_CHANNELS) {
    if (pulseWidth < CHANNEL_MIN) pulseWidth = CHANNEL_MIN;
    else if (pulseWidth > CHANNEL_MAX) pulseWidth = CHANNEL_MAX;
    ReceiverValue[channelIndex] = pulseWidth;
    channelIndex++;
  }
}

// ==== Read Receiver Values ====
void read_receiver() {
  noInterrupts();
  for (int i = 0; i < NUM_CHANNELS; i++) {
    channelValues[i] = ReceiverValue[i];
  }
  interrupts();
}

// ==== Kalman Filter - Fixed with References ====
void kalman_1d(float& KalmanState, float& KalmanUncertainty, float KalmanInput, float KalmanMeasurement) {
  // Prediction step
  KalmanState = KalmanState + dt * KalmanInput;
  KalmanUncertainty = KalmanUncertainty + dt * dt * 4 * 4;
  
  // Update step
  float KalmanGain = KalmanUncertainty / (KalmanUncertainty + 3 * 3);
  KalmanState = KalmanState + KalmanGain * (KalmanMeasurement - KalmanState);
  KalmanUncertainty = (1 - KalmanGain) * KalmanUncertainty;
  Kalman1DOutput[0] = KalmanState;
  Kalman1DOutput[1] = KalmanUncertainty;
}
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

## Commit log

2025-09-15 restructure the 3D file directory
    [Bicopter_Bottom_Plate v1.stl, Bicopter_Latest_Leg_Holder.stl, Bicopter_Main_Frame.stl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]
2025-09-21 -restructure the directory
    [BicopterLeft_Right_Hollow_Bottom.stl, Bicopter_FC_Middle_Holder.stl, Bicopter_Left_Right_v5.stl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]
2025-09-28 +added Bicopter motor section
    [Bicopter_Motor_section.stl]
2025-10-06 +added working 4 in 1 esc motor
2026-02-16 -remove aggress pid value
